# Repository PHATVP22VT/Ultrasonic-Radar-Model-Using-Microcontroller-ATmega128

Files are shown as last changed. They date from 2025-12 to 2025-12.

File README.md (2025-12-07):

# Authors: Hoang Tien Phat and Nguyen Nhat Quang
# Email contact: 
- phat.hoangtien@hcmut.edu.vn
- quang.nguyennhat2004@hcmut.edu.vn
# This project is for the Embedded Systems Design course of Ho Chi Minh University of Technology.
# Description:
The radar system uses ultrasonic waves to detect and locate objects within a 180-degree range, displaying information on an LCD screen and Laptop screen.

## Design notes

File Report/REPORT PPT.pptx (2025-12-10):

## DỰ ÁN THIẾT KẾ HỆ THỐNG NHÚNG

THIẾT KẾ HỆ THỐNG CẢM BIẾN SIÊU ÂM PHÁT HIỆN VẬT THỂ VÀ ĐO KHOẢNG CÁCH QUÉT 180⁰
NHÓM 2

## TỔNG QUAN HỆ THỐNG

Functional Requirement
FR1: Phát hiện vật thể
FR1.1: Cảm biến siêu âm có thể phát hiện vật thể.
FR1.2: Cảm biến siêu âm có thể đo được khoảng cách đến vật thể.
FR2: Hiển thị kết quả
FR2.1: Kết quả phát hiện vật thể trên màn LCD là “Object detected”.
FR2.2: Kết quả khoảng cách từ hệ thống đến vật thể được hiển thị trên màn LCD.
FR2.3: Kết quả phát hiện vật thể và khoảng cách được hiển thị trên màn hình laptop.
FR2.4: Nếu không có vật thể thì kết quả hiển thị sẽ là “No object”.
FR3: Thông báo phát hiện vật thể
FR3.1: Khi phát hiện vật thể thì buzzer sẽ kêu một tiếng “bíp”.
FR4: Khối xử lý
FR4.1: Nếu hệ thống hoạt động thì vi xử lý sẽ cho đèn led báo hiệu sáng.
FR4.2: Nút reset dùng để cài hệ thống hoạt động lại từ đầu.
FR5: Khối chuyển động
FR5.1: Servo motor sẽ chuyển động với góc quét thuận chiều kim đồng hồ hoặc ngược chiều kim đồng hồ tối đa 180 độ

## Nonfunctional Requirement

NFR1: YÊU CẦU HIỆU NĂNG (PERFORMANCE)
NFR1.1: Tốc độ quét của motor là 1 vòng trong 28 giây.
NFR1.2: Thời gian phản hồi của hệ thống kể từ lúc phát hiện vật thể nhỏ hơn 1 giây.
NFR1.3: Phạm vi phát hiện từ 2cm đến 40 cm.
NFR1.4: Độ tăng giảm góc quét là 2^o
NFR1.5: Nút nhấn có tuổi thọ là 50.000 nhấn và có chống rung bằng phần mềm.
NFR 1.6: Thời gian gửi dữ liệu uart đến laptop từ 4ms đến 9ms.
NFR 1.7: Công suất tiêu thụ tối đa là 1W
NFR2: CHI PHÍ
NFR2.1: Tổng chi phí cho linh kiện hệ thống khoảng 600.000 VNĐ
NFR2.2: Chi phí cho MCU nhỏ hơn 100.000 VNĐ
NFR2.3: Chi phí in mạch nhỏ hơn 200.000 VNĐ

## TỔNG QUAN HỆ THỐNG

Nonfunctional Requirement
NFR3: KÍCH THƯỚC VẬT LÝ
NFR3.1: Toàn bộ hệ thống có thể được sử dụng trên bàn làm việc, kích cỡ 10x10 cm.
NFR4: MÔI TRƯỜNG HOẠT ĐỘNG
NFR4.1: Hệ thống có thể hoạt động trong nhiệt độ phòng, khoảng 25-35 độ C.
NFR5: KHỐI LƯỢNG
NFR5.1: Tổng khối lượng của hệ thống phải nhỏ hơn 1 kg.
NFR6: ĐIỆN NĂNG TIÊU THỤ
NFR6.1: Hệ thống phải hoạt động với hai mức nguồn đầu vào: 5V DC cho cho các khối và 12V DC cho mạch ổn áp.
NFR6.2: Dòng tiêu thụ tổng của nguồn 5V phải nhỏ hơn 500mA.

## USE CASE

UC – 01: Chế độ thông thường
Mô tả: Khi hệ thống được cấp nguồn thì servo motor bắt đầu quay và cảm biến siêu âm sẽ bắt đầu tìm kiếm vật thể.
Các bước thực hiện:
1. Hệ thống được cấp nguồn.
2. LCD hiển thị “System ready” và Buzzer kêu 1 tiếng “bíp”.
3. Hệ thống bắt đầu qua từ 0^o-180^o sau đó quay 180^o-0^o.
4. LCD sẽ hiển thị 2 dòng, dòng 1 là trạng thái phát hiện vật thể, dòng 2 là góc quay hiện tại.
5. Nếu chưa phát hiện vật thể, LCD sẽ hiển thị dòng 1 là “No object”.
6. Khi phát hiện vật thể thì LCD hiển thị “Dist: xx cm” và còi sẽ kêu “bíp”.
7. Khi vật thể có tín hiệu ngay tầm đo tối đa và luân chuyển giữa hai trạng thái phát hiện thì sẽ là “Out range”.
Yêu cầu: Hệ thống được cấp nguồn.

## USE CASE

UC – 02: Chế độ tạm dừng.
Mô tả: Tạm dừng hệ thống.
Các bước thực hiện:
1. Khi hệ thống đang quay, kết quả góc quét sẽ được trả về laptop qua giao tiếp uart và hiển thị bằng dạng hình ảnh radar thông qua phần mềm processing.
2. Trên phần mềm processing sẽ có giao diện 3 nút “Stop”, “Menu”, “Select”. Nhấn nút “Stop” một lần thì servo motor tạm dừng, LCD hiển thị “System Stop”, nhấn nút “Stop” thêm lần nữa để hệ thống tiếp tục hoạt động.
Yêu cầu: Nhấn nút “Stop” trên giao diện processing.

## USE CASE

UC – 03: Chế độ thay đổi chiều quay
Mô tả: Hệ thống thay đổi chiều quét vật thể.
Các bước thực hiện:
1. Nhấn nút “Stop” để hệ thống tạm dừng.
2. Nhấn nút “Menu” trên giao diện processing để vào giao diện setting. LCD hiển thị dòng 1 “Current: xx” với xx là chiều quay hiện tại là Fwd hoặc Rvs tương ứng cùng chiều kìm đồng hồ hoặc ngược chiều kim đồng hồ. Dòng 2 hiển thị “Set: xx” với xx là chiều người dùng mong muốn.
3. Nhấn nút “Select” trên processing để chuyển đổi hai trạng thái Fwd hoặc Rvs trên dòng “Set: xx” của LCD.
4. Nhấn nút “Menu” để xác nhận chiều quay mong muốn, LCD sẽ hiện “Save OK!” và sau đó quay về trạng thái tạm dừng với LCD hiển thị “System Stop”.
5. Nhấn nút “Stop” để hệ thống quay theo chiều vừa được thiết lập.
Yêu cầu: Nhấn nút “Stop”, “Menu”, “Select”.

## BLOCK DIAGRAM

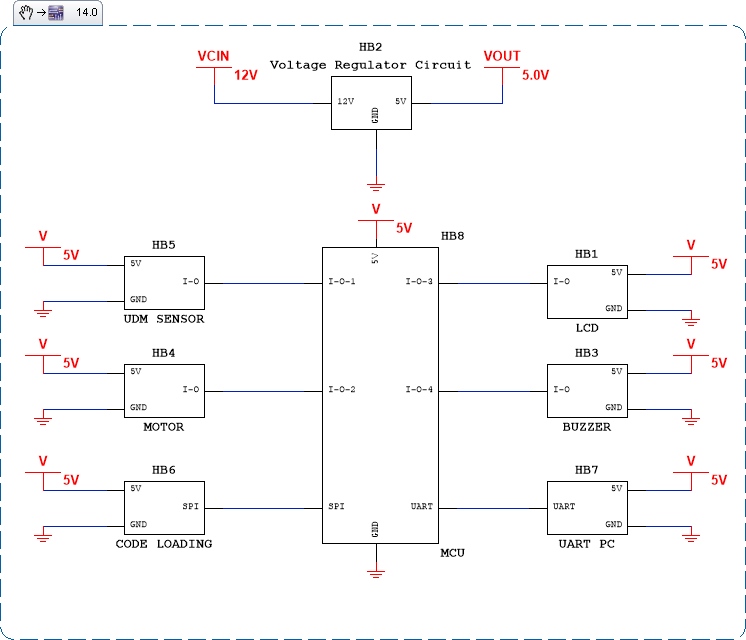
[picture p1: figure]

## KHỐI NGUỒN

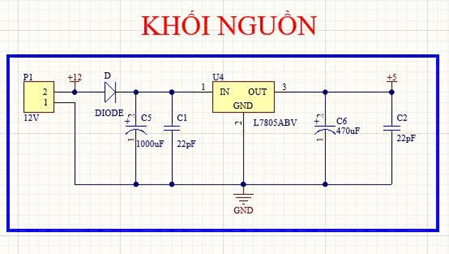
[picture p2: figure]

Schematic

## KHỐI HIỂN THỊ

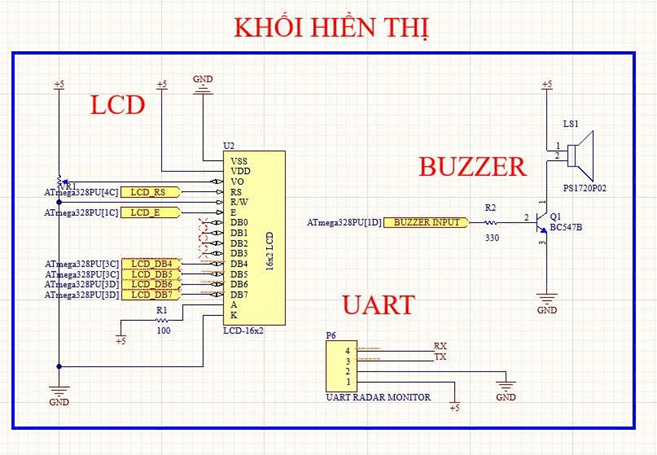
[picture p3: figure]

Schematic

## KHỐI VI ĐIỀU KHIỂN

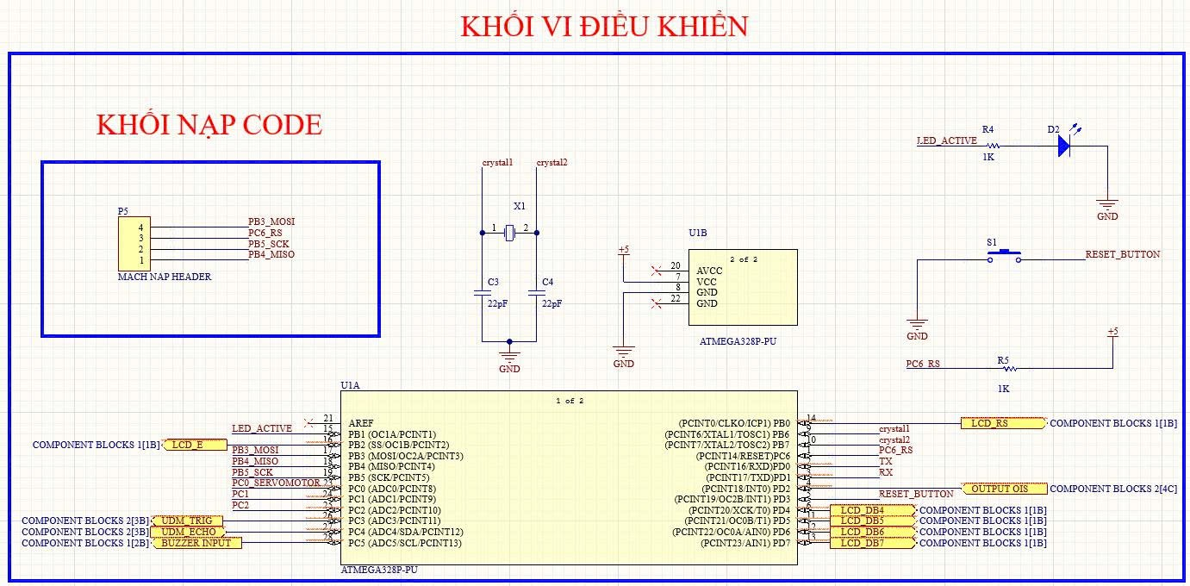
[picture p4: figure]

Schematic

## KHỐI DI CHUYỂN

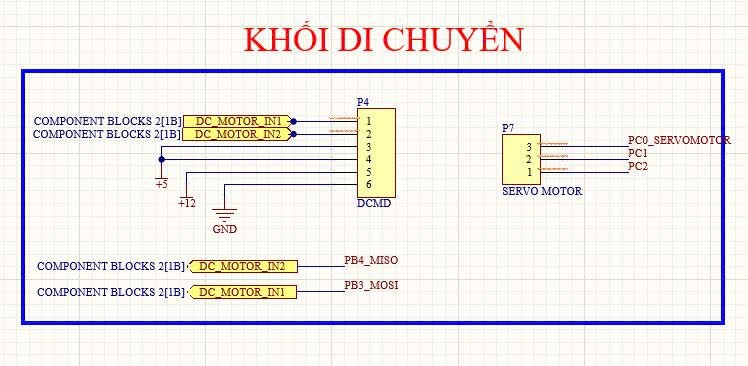
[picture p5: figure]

Schematic

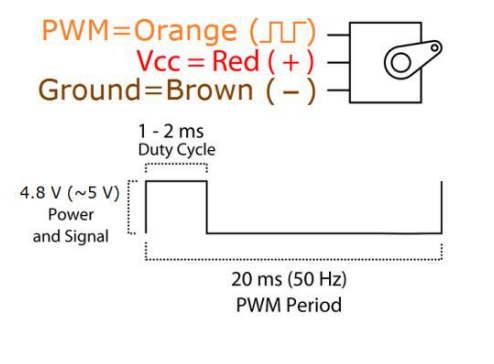
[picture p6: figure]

Chân kết nối

## KHỐI CẢM BIẾN

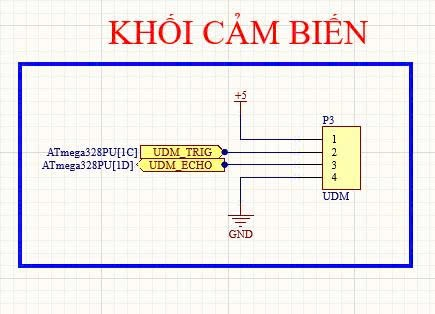
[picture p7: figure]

Schematic

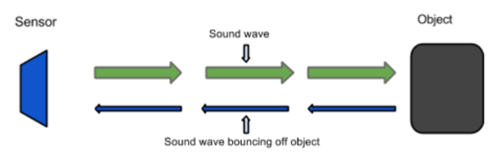
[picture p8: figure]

Hoạt động của cảm biến siêu âm

## TÍNH TOÁN THÔNG SỐ

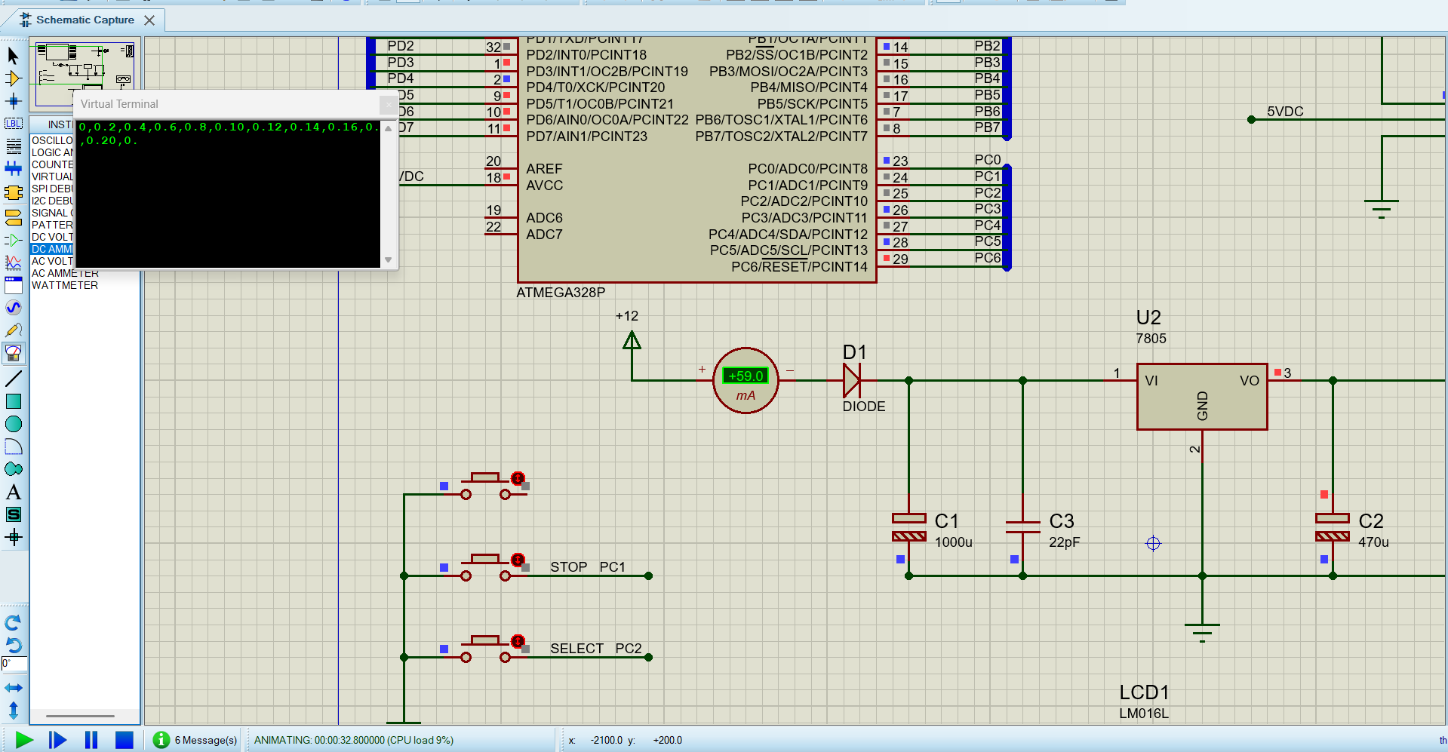
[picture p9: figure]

Dòng cung cấp toàn mạch là 59mA. Công suất toàn mạch là 12V x 59mA ≈0.7W

## LAYOUT

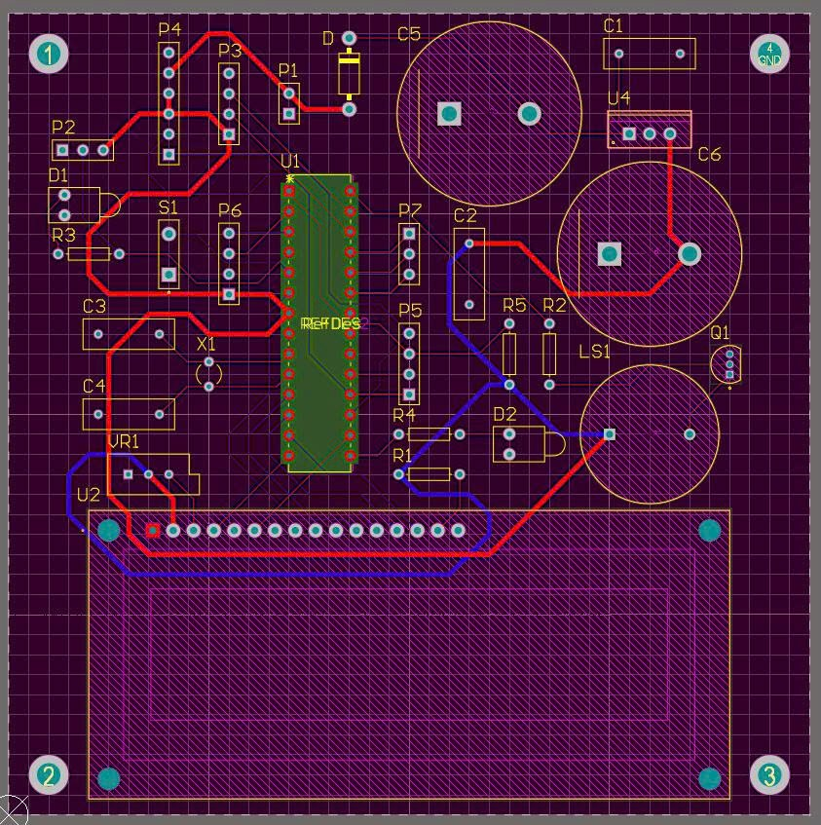
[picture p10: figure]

## THIẾT KẾ PHẦN MỀM

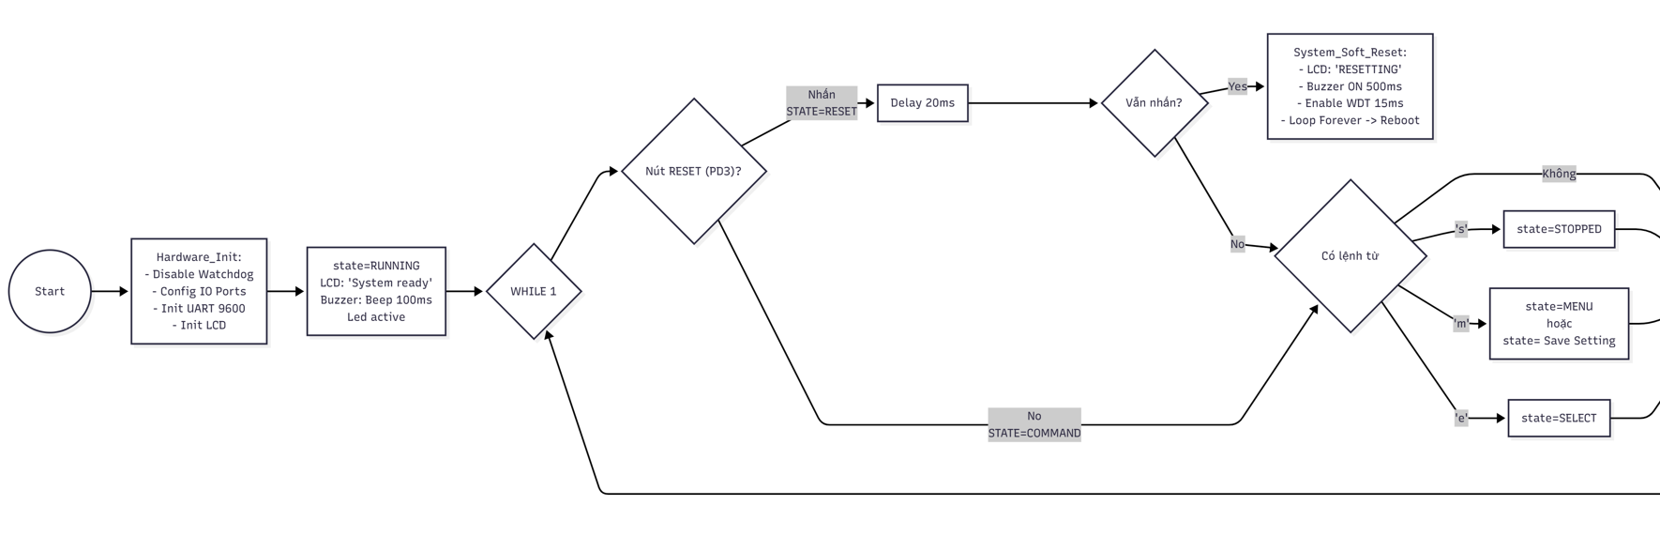
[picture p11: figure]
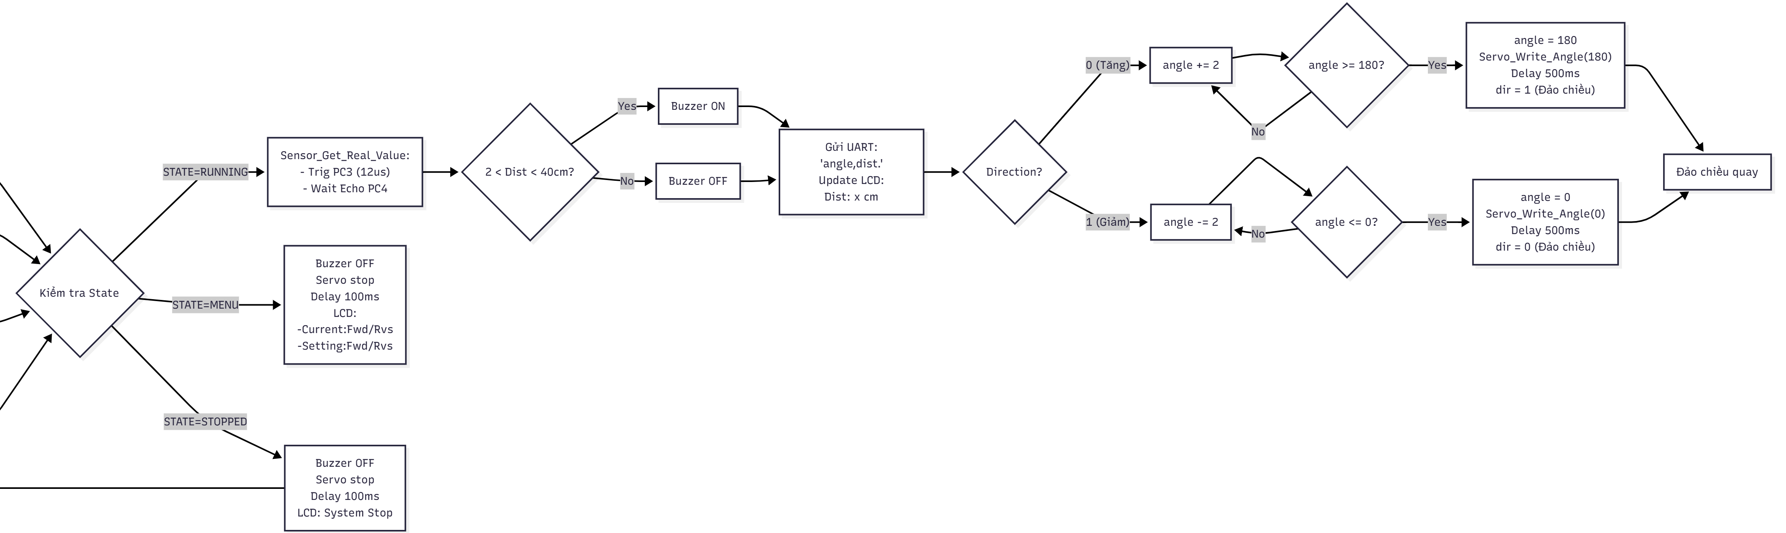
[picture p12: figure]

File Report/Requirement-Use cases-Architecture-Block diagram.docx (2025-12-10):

## 1.1. Requirement

### 1.1.1. Functional Requirement

| FUNCTIONAL REQUIREMENTS
FR1 | Phát hiện vật thể
FR2 | Hiển thị kết quả
FR3 | Thông báo phát hiện vật thể
FR4 | Khối xử lý
FR5 | Khối chuyển động

FR1: Phát hiện vật thể

- FR1.1: Cảm biến siêu âm có thể phát hiện vật thể.
- FR1.2: Cảm biến siêu âm có thể đo được khoảng cách đến vật thể.

FR2: Hiển thị kết quả

- FR2.1: Kết quả phát hiện vật thể trên màn LCD là “Object detected”.
- FR2.2: Kết quả khoảng cách từ hệ thống đến vật thể được hiển thị trên màn LCD.
- FR2.3: Kết quả phát hiện vật thể và khoảng cách được hiển thị trên màn hình laptop.
- FR2.4: Nếu không có vật thể thì kết quả hiển thị sẽ là “No object”.

FR3: Thông báo phát hiện vật thể

- FR3.1: Khi phát hiện vật thể thì buzzer sẽ kêu một tiếng “bíp”.

FR4: Khối xử lý

- FR4.1: Nếu hệ thống hoạt động thì vi xử lý sẽ cho đèn led báo hiệu sáng.
- FR4.2: Nút reset dùng để cài hệ thống hoạt động lại từ đầu.

FR5: Khối chuyển động

- FR5.1: Servo motor sẽ chuyển động với góc quét thuận chiều kim đồng hồ hoặc ngược chiều kim đồng hồ tối đa 180^o .

### 1.1.2. Nonfunctional Requirement

| NON-FUNCTIONAL REQUIREMENTS
NFR1 | HIỆU NĂNG
NFR2 | CHI PHÍ
NFR3 | KÍCH THƯỚC VẬT LÝ
NFR4 | MÔI TRƯỜNG HOẠT ĐỘNG
NFR5 | KHỐI LƯỢNG
NFR6 | ĐIỆN NĂNG TIÊU THỤ

NFR1: YÊU CẦU HIỆU NĂNG (PERFORMANCE)

- NFR1.1: Tốc độ quét của motor là 1 vòng trong 28 giây.
- NFR1.2: Thời gian phản hồi của hệ thống kể từ lúc phát hiện vật thể nhỏ hơn 1 giây.
- NFR1.3: Phạm vi phát hiện từ 2cm đến 40 cm.
- NFR1.4: Độ tăng giảm góc quét là 2^o
- NFR1.5: Nút nhấn có tuổi thọ là 50.000 nhấn và có chống rung bằng phần mềm.
- NFR 1.6: Thời gian gửi dữ liệu uart đến laptop từ 4ms đến 9ms.
- NFR 1.7: Công suất tối đa là 1W

NFR2: CHI PHÍ

- NFR2.1: Tổng chi phí cho linh kiện hệ thống khoảng 600.000 VNĐ
- NFR2.2: Chi phí cho MCU nhỏ hơn 100.000 VNĐ
- NFR2.3: Chi phí in mạch nhỏ hơn 200.000 VNĐ

NFR3: KÍCH THƯỚC VẬT LÝ

- NFR3.1: Toàn bộ hệ thống có thể được sử dụng trên bàn làm việc, kích cỡ 10x10 cm.

NFR4: MÔI TRƯỜNG HOẠT ĐỘNG

- NFR4.1: Hệ thống có thể hoạt động trong nhiệt độ phòng, khoảng 25-35 độ C.

NFR5: KHỐI LƯỢNG

- NFR5.1: Tổng khối lượng của hệ thống phải nhỏ hơn 1 kg.

NFR6: ĐIỆN NĂNG TIÊU THỤ

- NFR6.1: Hệ thống phải hoạt động với hai mức nguồn đầu vào: 5V DC cho cho các khối và 12V DC cho mạch ổn áp.
- NFR6.2: Dòng tiêu thụ tổng của nguồn 5V phải nhỏ hơn 500mA.

## 1.2. Use cases

- UC – 01: Chế độ thông thường
  - Mô tả: Khi hệ thống được cấp nguồn thì servo motor bắt đầu quay và cảm biến siêu âm sẽ bắt đầu tìm kiếm vật thể.
  - Các bước thực hiện:
    - Hệ thống được cấp nguồn.
    - LCD hiển thị “System ready” và Buzzer kêu 1 tiếng “bíp”.
    - Hệ thống bắt đầu qua từ 0^o -180^o sau đó quay 180^o -0^o .
    - LCD sẽ hiển thị 2 dòng, dòng 1 là trạng thái phát hiện vật thể, dòng 2 là góc quay hiện tại.
    - Nếu chưa phát hiện vật thể, LCD sẽ hiển thị dòng 1 là “No object”.
    - Khi phát hiện vật thể thì LCD hiển thị “Dist: xx cm” và còi sẽ kêu “bíp”.
    - Khi vật thể có tín hiệu ngay tầm đo tối đa và luân chuyển giữa hai trạng thái phát hiện thì sẽ là “Out range”.
  - Yêu cầu: Hệ thống được cấp nguồn.
- UC – 02: Chế độ tạm dừng.
  - Mô tả: Tạm dừng hệ thống.
  - Các bước thực hiện:
    - Khi hệ thống đang quay, kết quả góc quét sẽ được trả về laptop qua giao tiếp uart và hiển thị bằng dạng hình ảnh radar thông qua phần mềm processing.
    - Trên phần mềm processing sẽ có giao diện 3 nút “Stop”, “Menu”, “Select”. Nhấn nút “Stop” một lần thì servo motor tạm dừng, LCD hiển thị “System Stop”, nhấn nút “Stop” thêm lần nữa để hệ thống tiếp tục hoạt động.
  - Yêu cầu: Nhấn nút “Stop” trên giao diện processing.
- UC – 03: Chế độ thay đổi chiều quay
  - Mô tả: Hệ thống thay đổi chiều quét vật thể.
  - Các bước thực hiện:
    - Nhấn nút “Stop” để hệ thống tạm dừng.
    - Nhấn nút “Menu” trên giao diện processing để vào giao diện setting. LCD hiển thị dòng 1 “Current: xx” với xx là chiều quay hiện tại là Fwd hoặc Rvs tương ứng cùng chiều kìm đồng hồ hoặc ngược chiều kim đồng hồ. Dòng 2 hiển thị “Set: xx” với xx là chiều người dùng mong muốn.
    - Nhấn nút “Select” trên processing để chuyển đổi hai trạng thái Fwd hoặc Rvs trên dòng “Set: xx” của LCD.
    - Nhấn nút “Menu” để xác nhận chiều quay mong muốn, LCD sẽ hiện “Save OK!” và sau đó quay về trạng thái tạm dừng với LCD hiển thị “System Stop”.
    - Nhấn nút “Stop” để hệ thống quay theo chiều vừa được thiết lập.
  - Yêu cầu: Nhấn nút “Stop”, “Menu”, “Select”.

## 1.3. System Architecture

Kiến trúc hệ thống bao gồm các khối chính là Khối nguồn, Khối hiển thị, Khối vi điều khiển, Khối di chuyển, Khối cảm biến và Khối nạp code. Trong đó:

- Khối nguồn: Nguồn 12V và mạch ổn áp tạo nguồn 5V.
- Khối hiển thị: Hiển thị thông qua LCD, màn máy tính và thông báo bằng buzzer.
- Khối vi điều khiển: Thực hiện điều khiển các khối còn lại.
- Khối di chuyển: Servo motor quay 180^o kèm theo UDM sensor.
- Khối cảm biến: Cảm biến siêu âm dùng để cảm biến vật thể.
- Khối nạp code: Dùng để nạp code vào AVR thông qua giao tiếp SPI.

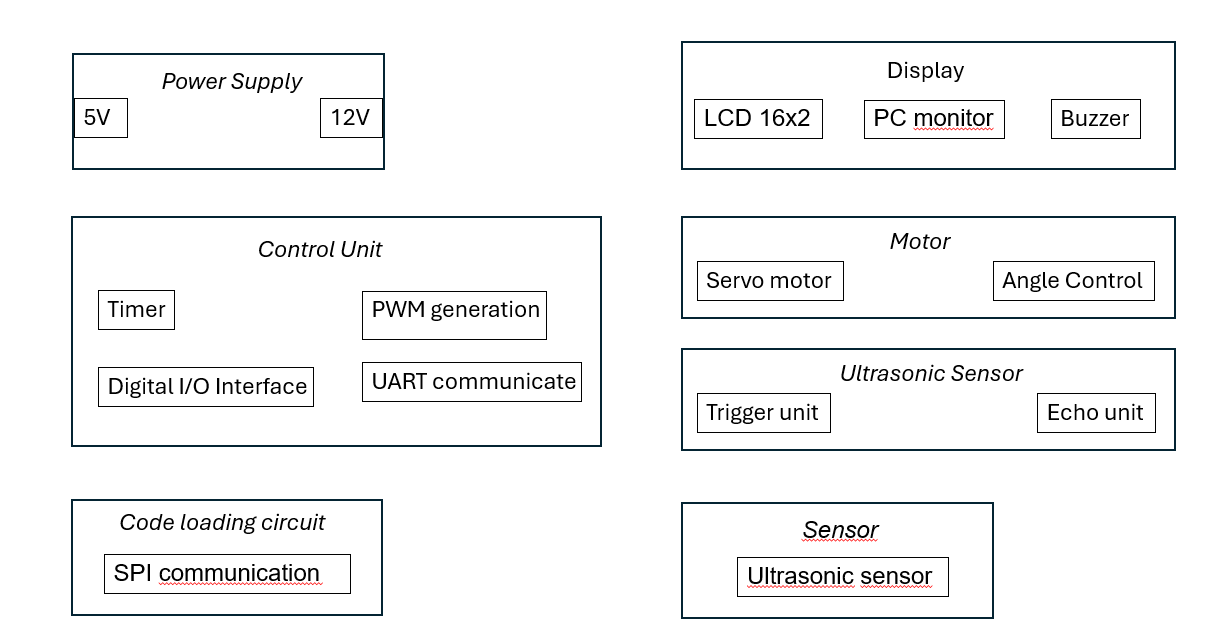
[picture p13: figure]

## 1.4. Block diagram

Block diagram thể hiện cách thức giao tiếp cũng như các khối nào nào là module input, các khối nào là module output.


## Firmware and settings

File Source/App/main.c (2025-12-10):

#include "../BSP/board.h"
#include "../Common/std_types.h"
#include "../Driver/Components/uart.h"
#include "../Driver/Devices/servo.h"
#include "../Driver/Devices/hcsr04.h"
#include "../Driver/Devices/lcd.h"
#include <util/delay.h>
#include <avr/wdt.h>

/* DEFINE TR?NG THÁI */
#define STATE_RUNNING 0
#define STATE_STOPPED 1
#define STATE_MENU    2

/* BI?N TOÀN C?C */
int angle = 0;
int direction = 0; // 0: Tang, 1: Giam
int distance = 0;
uint8 system_state = STATE_RUNNING;
uint8 menu_option = 0;

/* HÀM KH?I T?O T?NG */
void Hardware_Init_All(void) {
	MCUSR = 0;
	wdt_disable();

	Servo_Init();
	Ultrasonic_Init();
	UART_Init();
	LCD_Init();

	// Init LED & Buzzer & Button (Code ng?n nên ?? ?ây ho?c t?o file bsp_io.c)
	SENSOR_DDR |= (1 << BUZZER_PIN);
	SENSOR_PORT &= ~(1 << BUZZER_PIN);
	
	LED_DDR |= (1 << LED_PIN);
	LED_PORT |= (1 << LED_PIN);

	BTN_DDR &= ~(1 << RESET_BTN_BIT);
	BTN_PORT |= (1 << RESET_BTN_BIT);
}

void System_Soft_Reset(void) {
	LCD_Clear();
	LCD_Print_String("RESETTING...");
	SENSOR_PORT |= (1 << BUZZER_PIN);
	_delay_ms(500);
	SENSOR_PORT &= ~(1 << BUZZER_PIN);
	wdt_enable(WDTO_15MS);
	while(1) {}
}

void Draw_Menu_Screen(void) {
	LCD_Clear();
	LCD_Print_String_At(0, 0, "Cur:");
	if (direction == 0) LCD_Print_String("Fwd"); else LCD_Print_String("Rev");
	LCD_Print_String_At(1, 0, "Set:");
	if (menu_option == 0) LCD_Print_String("Fwd"); else LCD_Print_String("Rev");
}

int main(void) {
	Hardware_Init_All();
	
	LCD_Clear();
	LCD_Print_String("System Ready");
	SENSOR_PORT |= (1 << BUZZER_PIN); _delay_ms(100); SENSOR_PORT &= ~(1 << BUZZER_PIN);
	
	Servo_Write_Angle(0);
	_delay_ms(1000);
	LCD_Clear();

	while (1) {
		/* --- CHECK RESET --- */
		if (!(BTN_PIN_REG & (1 << RESET_BTN_BIT))) {
			_delay_ms(20);
			if (!(BTN_PIN_REG & (1 << RESET_BTN_BIT))) System_Soft_Reset();
		}

		/* --- X? LÝ L?NH T? UART --- */
		char cmd = UART_Get_Cmd();
		if (cmd != 0) {
			if (cmd == 's') {
				if (system_state == STATE_RUNNING) {
					system_state = STATE_STOPPED;
					LCD_Clear(); LCD_Print_String("System Stop");
					} else if (system_state == STATE_STOPPED) {
					system_state = STATE_RUNNING;
					LCD_Clear();
				}
			}
			else if (cmd == 'm') {
				if (system_state == STATE_STOPPED) {
					system_state = STATE_MENU;
					menu_option = direction; Draw_Menu_Screen();
					} else if (system_state == STATE_MENU) {
					direction = menu_option;
					LCD_Clear(); LCD_Print_String("Saved OK!"); _delay_ms(1000);
					system_state = STATE_STOPPED;
					LCD_Clear(); LCD_Print_String("System Stop");
				}
			}
			else if (cmd == 'e') {
				if (system_state == STATE_MENU) {
					menu_option = !menu_option; Draw_Menu_Screen();
				}
			}
			UART_Clear_Cmd();
		}

		/* --- LOGIC CHÍNH --- */
		if (system_state == STATE_RUNNING) {
			
			distance = Ultrasonic_Get_Distance();
			
			// Còi báo ??ng
			if (distance >= 2 && distance < 40) SENSOR_PORT ^= (1 << BUZZER_PIN);
			else SENSOR_PORT &= ~(1 << BUZZER_PIN);

			UART_Send_Radar_Data(angle, distance);
			LCD_Update_Smart(distance, angle);

			// Quét Servo
			if (direction == 0) { // T?ng
				angle += 2;
				if (angle >= 180) {
					angle = 180;
					direction = 1;
					Servo_Write_Angle(angle);
					_delay_ms(500);
				}
				} else { // Gi?m
				angle -= 2;
				if (angle <= 0) {
					angle = 0;
					direction = 0;
					Servo_Write_Angle(angle);
					_delay_ms(500);
				}
			}
			
			Servo_Write_Angle(angle);
			_delay_ms(30);

			} else {
			// Khi d?ng thì t?t còi
			SENSOR_PORT &= ~(1 << BUZZER_PIN);
			_delay_ms(100);
		}
	}
}

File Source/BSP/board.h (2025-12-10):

#ifndef BOARD_H
#define BOARD_H

#include <avr/io.h>

#define F_CPU 1000000UL

/* --- LCD CONFIG (Map chân t? lcd.h c? sang ?ây) --- */
#define LCD_CTRL_PORT PORTB
#define LCD_CTRL_DDR  DDRB
#define LCD_RS_PIN    PB0
#define LCD_E_PIN     PB2

#define LCD_DATA_PORT PORTD
#define LCD_DATA_DDR  DDRD
/* L?u ý: Code LCD dùng 4 bit cao (D4-D7) c?a PORTD */

/* --- SERVO CONFIG --- */
#define SERVO_DDR   DDRC
#define SERVO_PORT  PORTC
#define SERVO_PIN   PC0

/* --- ULTRASONIC SENSOR CONFIG --- */
#define SENSOR_DDR     DDRC
#define SENSOR_PORT    PORTC
#define SENSOR_PIN_REG PINC
#define TRIG_PIN       PC3
#define ECHO_PIN       PC4

/* --- BUZZER CONFIG --- */
#define BUZZER_PIN     PC5

/* --- BUTTON CONFIG --- */
#define BTN_PIN_REG    PIND
#define BTN_PORT       PORTD
#define BTN_DDR        DDRD
#define RESET_BTN_BIT  PD3

/* --- LED CONFIG --- */
#define LED_DDR     DDRB
#define LED_PORT    PORTB
#define LED_PIN     PB1

/* --- UART CONFIG --- */
#define BAUD 9600
#define UBRR_VAL ((F_CPU/8/BAUD)-1)

#endif
